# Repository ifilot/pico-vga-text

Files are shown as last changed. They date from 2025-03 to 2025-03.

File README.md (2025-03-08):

# PicoBeam: A Raspberry Pi Pico 2 based VGA Display






This project demonstrates how to drive a VGA display using the **Raspberry Pi
Pico 2**. The display uses a 640x480 pixel resolution with 16 colors (4-bit
color depth). The Raspberry Pi Pico communicates with the display via a single
8-bit interface latch and provides debugging via UART.

## Features

- **Resolution**: 640 x 480 pixels
- **Builtin Font**: Original Philips P2000C 12x8 bitmap font
- **Bitmapped graphics**: Support for printing individual pixels to the screen
- **Color Depth**: 4-bit (16 colors)
- **Refresh Rate**: ~72 Hz (using a 150 MHz clock with a x5 clock divider)
- **Interface**: Single 8-bit latch for display control
- **UART**: For debugging and communication
- **Beeper**: 1-bit beeper for simple audio feedback

> [!WARNING]
> **Do not connect this board to a CRT monitor unless you are absolutely sure
> that the monitor supports 72 Hz vertical sync at 640x480 resolution**. 
> Connecting this board to a CRT that does not support these specifications may
> cause **damage to the monitor** or result in **display instability**. 
> Always check your CRT monitor's specifications to confirm compatibility with
> 72 Hz VSync at 640x480 resolution before proceeding.

## How It Works

The Raspberry Pi Pico drives the display by receiving pixel data through an
8-bit latch interface, which updates the screen in real-time. By connecting
the Pico to the data bus of a CPU or microcontroller, instructions can be sent
to the Pico.

## Compilation instructions

### Toolchain

```bash
sudo apt install cmake gcc-arm-none-eabi libnewlib-arm-none-eabi build-essential libstdc++-arm-none-eabi-newlib
sudo git clone https://github.com/raspberrypi/pico-sdk.git /opt/pico-sdk
sudo git -C /opt/pico-sdk submodule update --init
RUN 'export PICO_SDK_PATH=/opt/pico-sdk' | tee -a /etc/profile.d/pico-sdk.sh
```

### Compiling

```bash
mkdir build && cd build
cmake ../src
make -j
```

## Instruction delays

The Pico requires a bit of processing time and one should be cautious not to
sent the data too fast. The following timings were found to give stable results
when using a simple (slow) voltage divider circuit. When connecting the Pico to
your specific setup, it is recommended to perform your own calibration to find
which delays provide stable results.

| Operation | Delay (μs) |
|---|---|
| Single characters | 150 |
| Large instructions (e.g., beeper or screen clear) | 2000 |

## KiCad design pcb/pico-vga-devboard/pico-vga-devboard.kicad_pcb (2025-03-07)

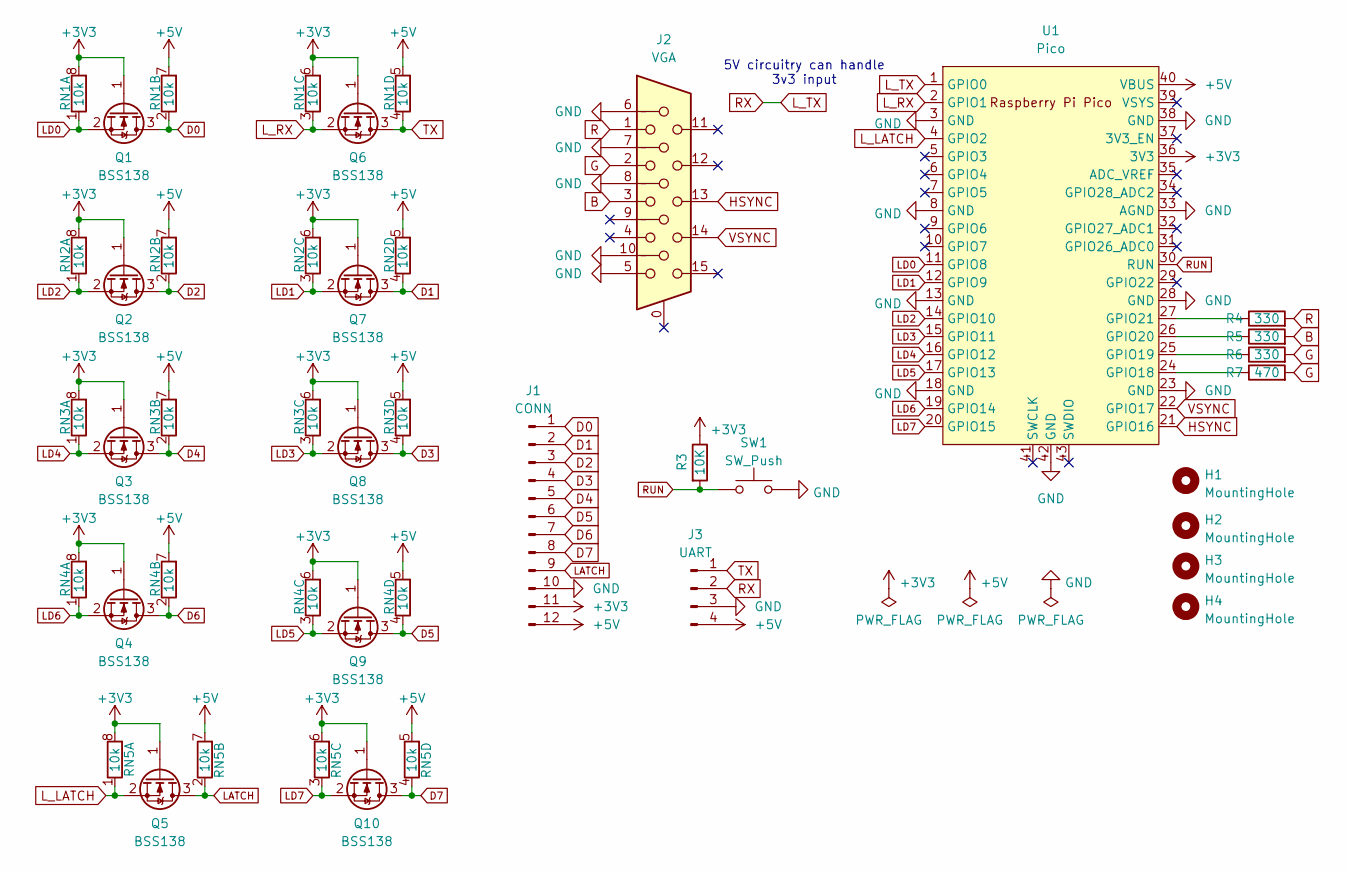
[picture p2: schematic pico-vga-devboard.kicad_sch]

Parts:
H1, H2, H3, H4: MountingHole; MountingHole_3.2mm_M3
J1: CONN; PinHeader_1x12_P2.54mm_Vertical
J2: VGA; 618015330923
J3: UART; PinHeader_1x04_P2.54mm_Vertical
Q1, Q2, Q3, Q4, Q5, Q6, Q7, Q8, Q9, Q10: BSS138; SOT-23; LCSC C78284
R3: 10K; R_0805_2012Metric_Pad1.20x1.40mm_HandSolder; LCSC C17414
R4, R5, R6: 330; R_0805_2012Metric_Pad1.20x1.40mm_HandSolder; LCSC C17630
R7: 470; R_0805_2012Metric_Pad1.20x1.40mm_HandSolder; LCSC C17710
RN1, RN2, RN3, RN4, RN5: 10k; R_Array_Convex_4x0603; LCSC C110924
SW1: SW_Push; SW_PUSH_6mm
U1: Pico; RPi_Pico_SMD_TH

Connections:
+3V3: J1.11, Q1.1 (G), Q2.1 (G), Q3.1 (G), Q4.1 (G), Q5.1 (G), Q6.1 (G), Q7.1 (G), Q8.1 (G), Q9.1 (G), Q10.1 (G), R3.1, RN1.6 (R3.2), RN1.8 (R1.2), RN2.6 (R3.2), RN2.8 (R1.2), RN3.6 (R3.2), RN3.8 (R1.2), RN4.6 (R3.2), RN4.8 (R1.2), RN5.6 (R3.2), RN5.8 (R1.2), U1.36 (3V3)
+5V: J1.12, J3.4, RN1.5 (R4.2), RN1.7 (R2.2), RN2.5 (R4.2), RN2.7 (R2.2), RN3.5 (R4.2), RN3.7 (R2.2), RN4.5 (R4.2), RN4.7 (R2.2), RN5.5 (R4.2), RN5.7 (R2.2), U1.40 (VBUS)
B: J2.3, R5.2
D0: J1.1, Q1.3 (D), RN1.2 (R2.1)
D1: J1.2, Q7.3 (D), RN2.4 (R4.1)
D2: J1.3, Q2.3 (D), RN2.2 (R2.1)
D3: J1.4, Q8.3 (D), RN3.4 (R4.1)
D4: J1.5, Q3.3 (D), RN3.2 (R2.1)
D5: J1.6, Q9.3 (D), RN4.4 (R4.1)
D6: J1.7, Q4.3 (D), RN4.2 (R2.1)
D7: J1.8, Q10.3 (D), RN5.4 (R4.1)
G: J2.2, R6.2, R7.2
GND: J1.10, J2.5, J2.6, J2.7, J2.8, J2.10, J3.3, SW1.2, U1.3 (GND), U1.8 (GND), U1.13 (GND), U1.18 (GND), U1.23 (GND), U1.28 (GND), U1.33 (AGND), U1.38 (GND), U1.42 (GND)
HSYNC: J2.13, U1.21 (GPIO16)
LATCH: J1.9, Q5.3 (D), RN5.2 (R2.1)
LD0: Q1.2 (S), RN1.1 (R1.1), U1.11 (GPIO8)
LD1: Q7.2 (S), RN2.3 (R3.1), U1.12 (GPIO9)
LD2: Q2.2 (S), RN2.1 (R1.1), U1.14 (GPIO10)
LD3: Q8.2 (S), RN3.3 (R3.1), U1.15 (GPIO11)
LD4: Q3.2 (S), RN3.1 (R1.1), U1.16 (GPIO12)
LD5: Q9.2 (S), RN4.3 (R3.1), U1.17 (GPIO13)
LD6: Q4.2 (S), RN4.1 (R1.1), U1.19 (GPIO14)
LD7: Q10.2 (S), RN5.3 (R3.1), U1.20 (GPIO15)
L_LATCH: Q5.2 (S), RN5.1 (R1.1), U1.4 (GPIO2)
L_RX: Q6.2 (S), RN1.3 (R3.1), U1.2 (GPIO1)
L_TX: J3.2, U1.1 (GPIO0)
unnamed: R7.1, U1.24 (GPIO18)
unnamed: R6.1, U1.25 (GPIO19)
unnamed: R5.1, U1.26 (GPIO20)
unnamed: R4.1, U1.27 (GPIO21)
R: J2.1, R4.2
RUN: R3.2, SW1.1, U1.30 (RUN)
TX: J3.1, Q6.3 (D), RN1.4 (R4.1)
VSYNC: J2.14, U1.22 (GPIO17)

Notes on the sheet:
5V circuitry can handle 3v3 input

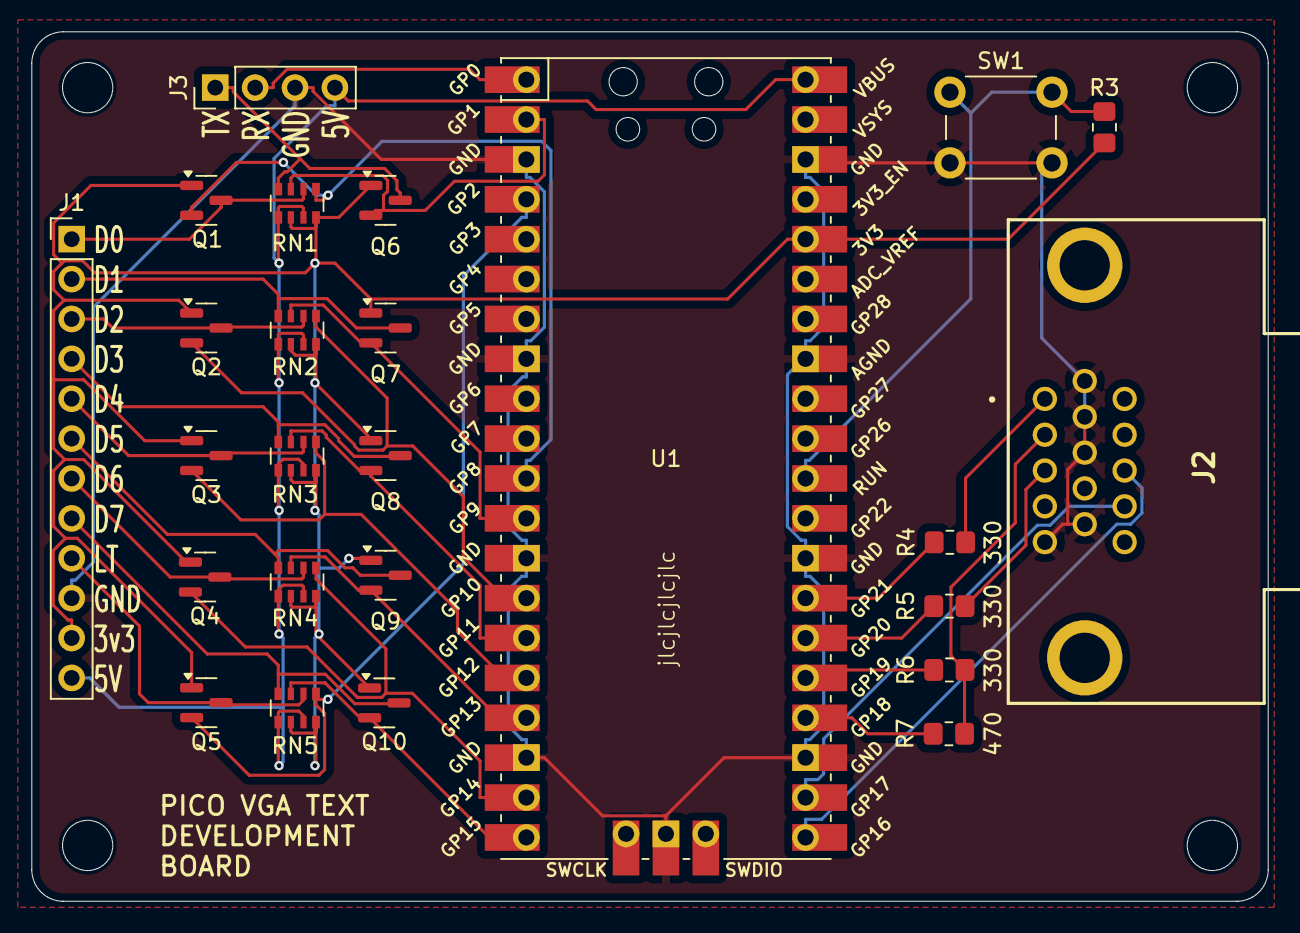
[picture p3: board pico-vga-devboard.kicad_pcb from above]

Board: 2 copper layers, 78.7 x 55.4 mm, 29 parts (0 on the bottom side), 34 nets.

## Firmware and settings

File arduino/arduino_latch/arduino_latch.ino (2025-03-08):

// Define delays for different types of operations (in microseconds)
static const uint8_t chardelay = 150;   // Delay for sending simple characters
static const uint8_t longdelay = 2000;  // Delay for long instructions (e.g., screen clear, beep)
static const uint8_t cmdbytedelay = 150;
static const uint8_t pixdelay = 200;    // Delay for sending pixel data

// Screen dimensions
#define SCREEN_WIDTH  640
#define SCREEN_HEIGHT 480

// Setup function - Initializes serial communication and configures output pins
void setup() {
  Serial.begin(115200);  // USB Serial (for debugging)
  Serial1.begin(115200); // Hardware Serial (for communication with external devices)

  // Set PB4-PB7 (D8-D11) and PF4-PF7 (A3-A0) as outputs
  DDRB |= 0b11110000;
  DDRF |= 0b11110000;

  // Configure latch pin (PD1) as output
  pinMode(2, OUTPUT);  
  digitalWrite(2, LOW); // Ensure latch starts low
}

// Function to send a character via parallel port with a latch pulse
void send_char(char val, unsigned int delay) {
  PORTB = (PORTB & 0x0F) | ((val & 0x0F) << 4);  // Send lower nibble to PB4-PB7
  PORTF = (PORTF & 0x0F) | ((val & 0xF0));       // Send upper nibble to PF4-PF7

  // Pulse the latch signal (D2) to indicate data is ready
  digitalWrite(2, HIGH);
  digitalWrite(2, LOW); // End latch pulse
  delayMicroseconds(delay);
}

// Function to handle serial communication between Serial (USB) and Serial1 (external device)
void handle_serial() {
  // Forward data from Serial1 (external device) to Serial (computer)
  while (Serial1.available()) {
    char incomingByte = Serial1.read();
    Serial.write(incomingByte);
  }

  // Forward data from Serial (computer) to Serial1 (external device)
  while (Serial.available()) {
    char outgoingByte = Serial.read();
    Serial1.write(outgoingByte);
  }
}

// Function to draw a full-screen text test pattern
void draw_text() {
  static uint8_t val = ' ';

  handle_serial();

  send_char(0xFF, longdelay); // Clear screen
  send_char(0xA0, longdelay); // Beep
  send_char(0x90, chardelay); // Set background to black

  // Draw characters in different foreground colors (0x81-0x8F)
  for(uint8_t i = 0x81; i <= 0x8F; i++) {
    send_char(i, chardelay);
    for(char val = ' '; val <= '~'; val++) { // ASCII printable range
      send_char(val, chardelay);
    }
  }

  handle_serial();

  send_char(0x80, chardelay); // Set foreground to black
  for(uint8_t i = 0x91; i <= 0x9F; i++) {
    send_char(i, chardelay);
    for(char val = ' '; val <= '~'; val++) {
      send_char(val, chardelay);
    }
  }

  handle_serial();
}

// Function to generate a 32-bit pixel command
uint32_t generate_pixel_command(uint16_t x, uint16_t y, uint8_t color) {
    return ((uint32_t)(color & 0x0F) << 28) |   // 4-bit color at bits 31-28
           ((uint32_t)(y & 0x3FF) << 18)    |   // 10-bit Y position at bits 27-18
           ((uint32_t)(x & 0x3FF) << 8)     |   // 10-bit X position at bits 17-8
           ((uint32_t)0xB0 & 0xFF);             // 8-bit control byte at bits 7-0
}

// Function to send a 32-bit pixel instruction over parallel port
void send_pixelword(uint32_t instruction) {
  send_char(instruction, cmdbytedelay);         // Send least significant byte
  send_char((instruction >> 8), cmdbytedelay);  // Send next byte
  send_char((instruction >> 16), cmdbytedelay); // Send next byte
  send_char((instruction >> 24), pixdelay);  // Send most significant byte
}

// Function to draw a filled square at (x,y) with a given size and color
void draw_square(uint16_t x, uint16_t y, uint16_t size, uint8_t color) {
    // Ensure the square stays within bounds
    if (x + size > SCREEN_WIDTH) size = SCREEN_WIDTH - x;
    if (y + size > SCREEN_HEIGHT) size = SCREEN_HEIGHT - y;

    // Loop through each pixel in the square
    for (uint16_t i = 0; i < size; i++) {
        for (uint16_t j = 0; j < size; j++) {
            uint32_t instruction = generate_pixel_command(x + i, y + j, color);
            send_pixelword(instruction);
            handle_serial(); // Process serial communication during drawing
        }
    }
}

// Function to draw a horizontal line at (x,y) with a given length and color
void draw_line(uint16_t x, uint16_t y, uint16_t size, uint8_t color) {
    // Ensure the line stays within bounds
    if (x + size > SCREEN_WIDTH) size = SCREEN_WIDTH - x;
    if (y >= SCREEN_HEIGHT) return; // Ensure y is within bounds

    // Loop to draw the line
    for (uint16_t i = 0; i < size; i++) {
        uint32_t instruction = generate_pixel_command(x + i, y, color);
        send_pixelword(instruction);
        handle_serial(); // Process serial communication during drawing
    }
}

// Function to draw a graphical test pattern
void draw_graph() {
  send_char(0xFF, longdelay); // Clear screen
  send_char(0xA0, longdelay); // Beep
  
  const uint16_t sz = 5; // Square size

  // Draw corner squares
  draw_square(0, 0, sz, 0x0F);
  draw_square(0, SCREEN_HEIGHT - sz - 1, sz, 0x0F);
  draw_square(SCREEN_WIDTH - sz - 1, 0, sz, 0x0F);
  draw_square(SCREEN_WIDTH - sz - 1, SCREEN_HEIGHT - sz - 1, sz, 0x0F);

  // Draw color test bars
  for(uint8_t i = 1; i <= 16; i++) {
    draw_square(50 + i * 15, 50, 10, i);
  }

  handle_serial();
}

// Main loop function - alternates between text and graphical tests
void loop() {
  draw_text();   // Draw text pattern
  _delay_ms(3000); 

  draw_graph();  // Draw graphical pattern
  _delay_ms(5000);
}

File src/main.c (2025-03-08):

/**
 *
 * VGA Display Driver with Multicore Processing
 *
 * HARDWARE CONNECTIONS:
 *  - GPIO 16 ---> VGA Hsync
 *  - GPIO 17 ---> VGA Vsync
 *  - GPIO 18 ---> 470-ohm resistor ---> VGA Green
 *  - GPIO 19 ---> 330-ohm resistor ---> VGA Green
 *  - GPIO 20 ---> 330-ohm resistor ---> VGA Blue
 *  - GPIO 21 ---> 330-ohm resistor ---> VGA Red
 *  - RP2040 GND ---> VGA GND
 *
 * RESOURCES USED:
 *  - PIO state machines 0, 1, and 2 on PIO instance 0
 *  - DMA channels obtained via claim mechanism
 *  - 153.6 kBytes of RAM (for pixel color data)
 *
 * Protothreads v1.1.3
 * Threads:
 * Core 0:
 *  - VGA display
 *  - Blink LED25
 * Core 1:
 *  - Toggle GPIO 4
 *  - Serial I/O
 */

#include <stdio.h>
#include <stdlib.h>
#include <pico/stdlib.h>
#include <hardware/pio.h>
#include <hardware/dma.h>
#include <hardware/sync.h>
#include <hardware/timer.h>
#include <hardware/pwm.h>
#include <hardware/clocks.h>
#include <pico/multicore.h>
#include <string.h>

#include "vga.h"
#include "latch.pio.h"
#include "protothreads.h"
#include "api.h"
 
char ch;
bool flag_latch = false;

// ==================================================
// === VGA Graphics Thread (Core 0) ===
// ==================================================
static PT_THREAD(protothread_graphics(struct pt *pt)) {
    PT_BEGIN(pt);

    while (true) {
        // Draw new character if received
        if (flag_latch) {
            parse_input(ch);

            // only release when char is done
            flag_latch = false;
        }

        // Yield to allow other threads to run
        PT_YIELD_usec(100);
    }
    PT_END(pt);
}

// ==================================================
// === LED Blink Thread (Core 0) ===
// ==================================================
static PT_THREAD(protothread_toggle25(struct pt *pt)) {
    PT_BEGIN(pt);
    static bool LED_state = false;

    // Initialize onboard LED (GPIO 25)
    gpio_init(25);
    gpio_set_dir(25, GPIO_OUT);
    gpio_put(25, true);

    PT_INTERVAL_INIT();

    while (1) {
        // Toggle LED every 100ms
        PT_YIELD_INTERVAL(100000);
        LED_state = !LED_state;
        gpio_put(25, LED_state);
    }
    PT_END(pt);
}

// ==================================================
//            Serial Input Thread (Core 1) 
// ==================================================
static PT_THREAD(protothread_serial(struct pt *pt)) {
    PT_BEGIN(pt);

    while (true) {
        // Spawn a thread to handle non-blocking serial write
        serial_write;

        // Spawn a thread to handle non-blocking serial read
        serial_read;

        PT_YIELD(pt);
    }
    PT_END(pt);
}

// ==================================================
//            Latch Input Thread (Core 1) 
// ==================================================
static PT_THREAD(protothread_latch(struct pt *pt)) {
    PT_BEGIN(pt);

    // Choose PIO and state machine
    PIO pio = pio1;
    uint sm = 0;

    // Define latch pin (GPIO 2) and data pins (GPIO 8-15)
    const uint latch_pin = 2;
    const uint data_base_pin = 8;

    // Initialize PIO program
    uint offset = pio_add_program(pio, &latch_program);
    latch_program_init(pio, sm, offset, latch_pin, data_base_pin);

    while (true) {
        if(!pio_sm_is_rx_fifo_empty(pio, sm) && !flag_latch) {
            ch = pio_sm_get(pio, sm);
            flag_latch = true;
        } else {
            PT_YIELD(pt);
        }
    }
    PT_END(pt);
}

// ==================================================
//            Latch Input Thread (Core 1) 
// ==================================================
static PT_THREAD(protothread_beeper(struct pt *pt)) {
    PT_BEGIN(pt);

    static uint64_t start_time;

    uint buzzer_pin = 3;
    uint freq = 726;
    float duty_cycle = 0.2;

    gpio_set_function(buzzer_pin, GPIO_FUNC_PWM);  // Set GPIO to PWM mode
    uint slice = pwm_gpio_to_slice_num(buzzer_pin);  // Get PWM slice
    uint channel = pwm_gpio_to_channel(buzzer_pin);  // Get PWM channel

    uint32_t clkdiv = 50; // Clock divider (adjustable for fine tuning)
    uint32_t wrap = (clock_get_hz(clk_sys) / (clkdiv * freq)) - 1;
    
    pwm_set_clkdiv(slice, clkdiv);  // Set clock divider
    pwm_set_wrap(slice, wrap);  // Set PWM frequency
    pwm_set_chan_level(slice, channel, (uint16_t)(wrap * duty_cycle));  // Set duty cycle

    while (true) {
        PT_YIELD_UNTIL(pt, flag_beep && !flag_beeping);
            flag_beep = false;
            flag_beeping = true;
            start_time = time_us_64(); 
            pwm_set_enabled(slice, true);  // Enable PWM
            printf("BEEP!\n");

        PT_YIELD_UNTIL(pt, flag_beeping && ((time_us_64() - start_time) >= (200 * 1000)));

            pwm_set_enabled(slice, false);
            flag_beeping = false;
    }
    PT_END(pt);
}

/**
 * @brief Main function for CORE 1
 * 
 */
void core1_main() {
    pt_add_thread(protothread_serial);
    pt_add_thread(protothread_latch);
    pt_add_thread(protothread_beeper);
    pt_schedule_start;
    // Never exits
}

/**
 * @brief Main function for CORE 2
 * 
 * @return int exit status
 */
int main() {
    // Initialize standard I/O
    stdio_init_all();
    printf("\nPICO2 VGA INITIALIZED\n");

    // Initialize VGA display
    init_screen();

    // Start core 1 processing
    multicore_reset_core1();
    multicore_launch_core1(&core1_main);

    // Add threads for core 0
    pt_add_thread(protothread_graphics);
    pt_add_thread(protothread_toggle25);

    // Start thread scheduling (never exits)
    pt_schedule_start;
} 

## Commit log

2025-03-07 Fixing font layout to 12x8
    [main.c, p2000cfont.py, testscreen.py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]
2025-03-07 Implementing control characters for color swaps
    [arduino_latch.ino, main.c]
2025-03-07 Adding development board
    [pico-vga-devboard-B_Cu.gbr, pico-vga-devboard-B_Mask.gbr, pico-vga-devboard-B_Paste.gbr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]
2025-03-07 Adding buzzer and refactoring code
    [arduino_latch.ino, main.c]

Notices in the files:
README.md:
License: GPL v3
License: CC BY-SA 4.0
